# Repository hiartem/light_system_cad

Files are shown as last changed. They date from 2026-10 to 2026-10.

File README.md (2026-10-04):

# light_system_cad

3D-printable enclosure for an ESP32-S3 based LED light controller, modelled in FreeCAD.
The whole model is generated by a single parametric Python script, so every dimension
can be changed and the case rebuilt in seconds.

Outer size: **116.2 × 65.4 × 39.1 mm** (base + screw-down lid).

## Components

| Component | Part | Mounting |
|---|---|---|
| Controller | ESP32-S3-DevKitC-1 | Rests on end supports with side guides; two USB-C openings in the end wall |
| Display | OLED 1.54" 128×64, 7-pin (SPI) | Under the lid, M2 self-tapping screws into bosses; chamfered viewing window |
| Input | Bourns PEC11R-4115F-S0018 rotary encoder with push switch | M9 bushing through the lid, printed knob with D-bore |
| Power supply | LM2596S 5 V buck module | Floor standoffs, M3 self-tapping |
| Power input | 5.5×2.1 mm DC panel jack, M8×1 thread | End wall |
| Power switch | SMRS-101 mini rocker | Snap-in cutout in the end wall |
| LED drivers | 2× IRFR120N (FR120N) MOSFET module | Floor standoffs, M3 self-tapping, one each side of the ESP32 |
| LED outputs | 2× Amass XT60E-F (female, panel mount) | Mounted externally on the long walls, M3 screws + nuts |

Other features:

- Lid fixed with 4× M3 countersunk screws into corner bosses, with a locating lip
- Ventilation slots on both long walls and in the lid
- Lid holes for the ESP32 BOOT / RST buttons and RGB LED
- Two keyhole slots in the bottom for wall mounting (92.2 mm apart)
- Recesses for Ø8 mm adhesive rubber feet

## Power wiring

```
DC adapter ─► DC jack ─► rocker switch ─┬─► LM2596S (5 V) ─► ESP32-S3 5V pin
                                        ├─► MOSFET 1 VIN ─► XT60 #1 ─► LED strip 1
                                        └─► MOSFET 2 VIN ─► XT60 #2 ─► LED strip 2
```

The LED strips run at the adapter voltage. Choose an adapter rated for both strips plus
the controller. MOSFET signal inputs go to two PWM-capable ESP32 GPIOs. When powering
the ESP32 through its 5V pin, check that your board revision has a diode between 5V and
USB before you plug in USB for programming.

## Files

| File | Description |
|---|---|
| `esp32s3_case.py` | Parametric build script (source of truth) |
| `ESP32S3_Case.FCStd` | FreeCAD document with the case and reference models of all components |
| `ESP32S3_Case_base.stl` | Base, print-ready |
| `ESP32S3_Case_lid.stl` | Lid, already in print orientation (outer face on the bed) |
| `ESP32S3_Case_knob.stl` | Encoder knob, already in print orientation |

## Rebuilding the model

In FreeCAD, run `esp32s3_case.py` via **Macro → Macros… → Execute**, or from the Python console:

```python
p = "/path/to/light_system_cad/esp32s3_case.py"; exec(open(p).read(), {"__file__": p})
```

Headless, without the GUI (geometry and STLs only: part colours are stored by the GUI,
so a headless rebuild saves an all-gray `.FCStd`. Rebuild inside FreeCAD to restore them):

```sh
freecadcmd -c 'p="/path/to/light_system_cad/esp32s3_case.py"; exec(open(p).read(), {"__file__": p})'
```

The script rebuilds the document, checks every part pair for interference and writes
`ESP32S3_Case.FCStd` and the STLs **next to itself**. No paths need editing.

All dimensions are parameters at the top of the script. Values marked **verify** are
typical figures for those parts. Measure your components and adjust them before
printing: the OLED, encoder, LM2596S and MOSFET module sizes and hole positions, the
switch cutout, the XT60E-F body, and the USB-C port spacing (`usb_dy`).

## Printing

Tested target: Bambu Lab printers (fits even the A1 mini).

- Material: **PETG** recommended (PLA OK for low loads, ASA for hot locations)
- 0.4 mm nozzle, 0.2 mm layers (0.16 mm for the knob), 4 walls, 15–20 % gyroid infill
- No supports needed for any part
- Base: floor on the bed. Lid: outer face on the bed. Knob: as exported

## Hardware

| Qty | Item | Use |
|---|---|---|
| 4 | M3×12–16 countersunk screw | Lid |
| 4 | M2×5 self-tapping screw | OLED |
| 6 | M3×6 self-tapping screw | LM2596S, MOSFET modules |
| 4 | M3×8 screw + nut | XT60E-F sockets |
| 4 | Ø8 mm adhesive rubber foot | Bottom |
| 2 | Ø3.5–4 mm pan-head screw + wall plug | Wall mounting |

## License

GPL-3.0, see [LICENSE](LICENSE).

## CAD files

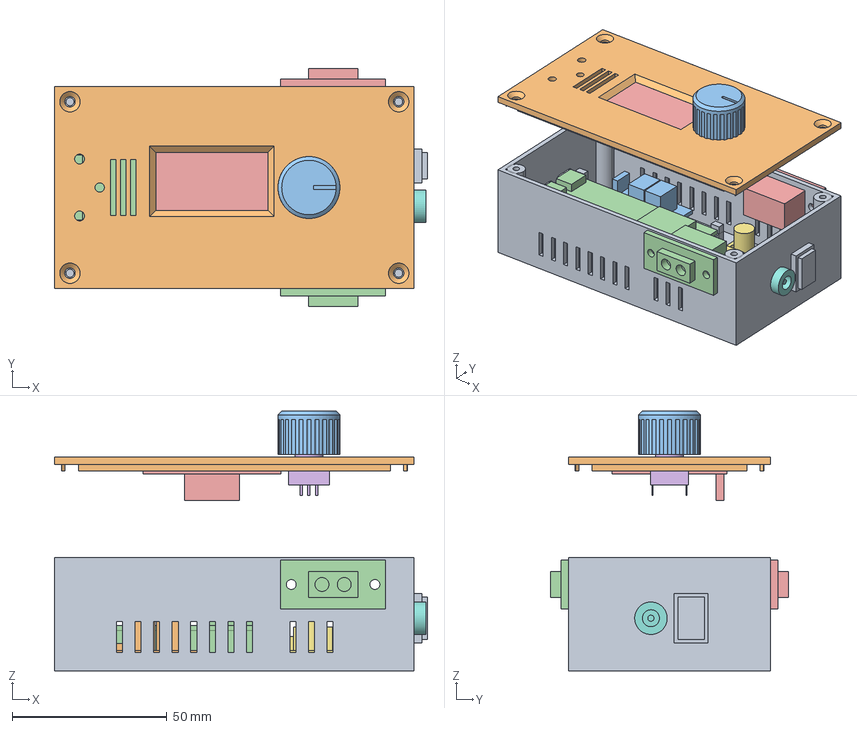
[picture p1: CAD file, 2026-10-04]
ESP32S3_Case.FCStd
120.5 x 76.8 x 83.9 mm
Case_Base
Case_Lid
Encoder_Knob
ESP32S3_DevKitC1_Ref
OLED_1in54_128x64_Ref
Encoder_PEC11R_4115F_Ref
LM2596S_5V_Module_Ref
DC_Jack_M8_5521_Ref
Switch_SMRS101_Ref
MOSFET_IRFR120N_1_Ref
MOSFET_IRFR120N_2_Ref
XT60E_F_1_Ref
XT60E_F_2_Ref

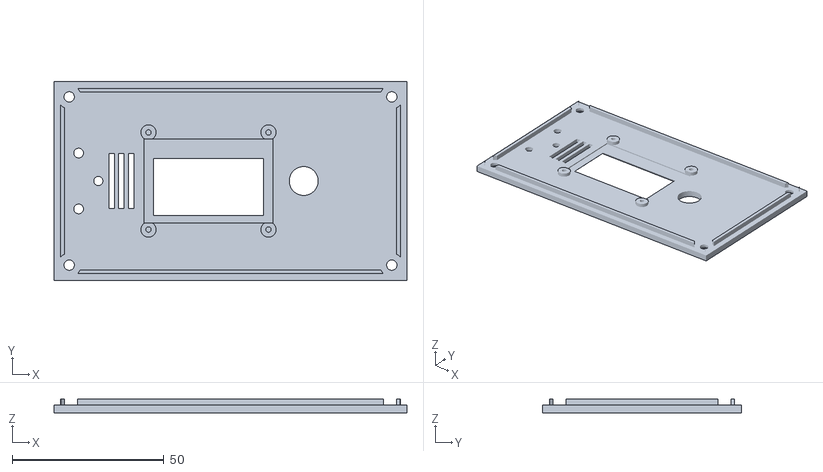
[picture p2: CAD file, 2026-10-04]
ESP32S3_Case_lid.stl
116.2 x 65.4 x 4.50

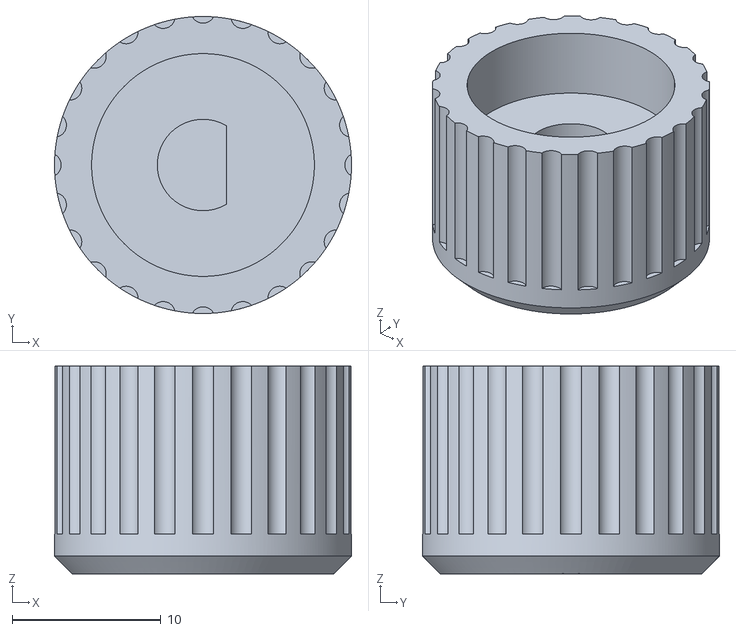
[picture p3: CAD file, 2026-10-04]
ESP32S3_Case_knob.stl
20.0 x 20.0 x 14.0

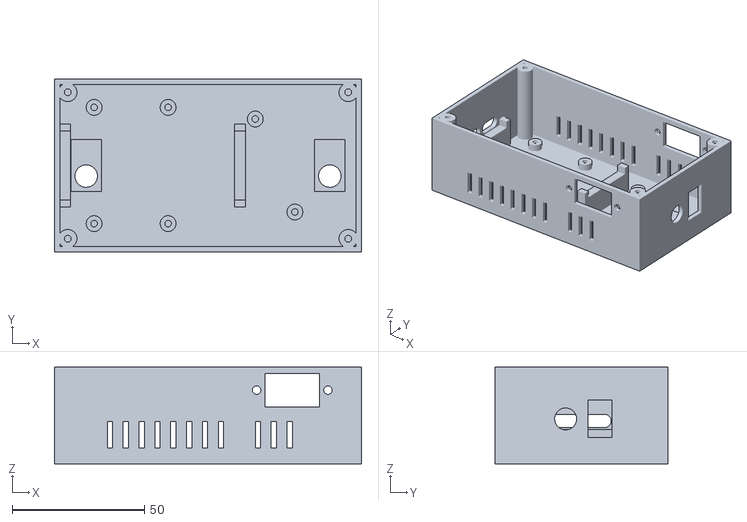
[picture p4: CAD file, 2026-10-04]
ESP32S3_Case_base.stl
116.2 x 65.4 x 36.6

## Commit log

2026-10-04 Add parametric ESP32-S3 light system case
    FreeCAD model of an enclosure for ESP32-S3-DevKitC-1 with 1.54" OLED,
    PEC11R encoder + knob, LM2596S 5V buck module, DC jack, SMRS-101 switch,
    two IRFR120N MOSFET modules with XT60E-F outputs, USB-C openings,
    screw-down lid and wall-mount keyholes.
    - esp32s3_case.py: parametric build script (run inside FreeCAD)
    - ESP32S3_Case.FCStd: FreeCAD document
    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
    [ESP32S3_Case.FCStd, ESP32S3_Case_base.stl, ESP32S3_Case_knob.stl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]
2026-10-04 Describe project in README
    Add component list, power wiring, file overview, rebuild instructions,
    print settings and hardware list.
2026-10-04 Save output next to script and export lid in print orientation
    - Resolve output folder from the script location instead of a
    hard-coded path; fail with a hint if it cannot be determined
    - Export lid STL flipped (outer face on bed) to avoid floating
    regions in the slicer
    - Warn when run headless, since part colours are not saved
    - Update README rebuild instructions accordingly
    [ESP32S3_Case.FCStd, ESP32S3_Case_lid.stl]
